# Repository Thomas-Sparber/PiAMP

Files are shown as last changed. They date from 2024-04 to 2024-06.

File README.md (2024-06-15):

# PiAMP



PiAMP is a DIY guitar amplifier which uses a neural network to emulate the sound of *any* guitar amplifier or pedal.

It consists of the following components
 - **Raspberry PI** which processes the audio, provides bluetooth connection and receives signals from the controls and footswitch
 - **HifibBerry DAC+ ADC** is the audio interface used for high quality audio
 - **Power amp** which converts the low level audio signal into a signal which can be fed into a speaker
 - **Speakers/Cabinet**
 - **Screen and controls** which allow to set the current Amp model, cabinet and other controls (gain, bas, mid, etc.)
 - **Footswitch** which allows to quickly switch between saved channels
 - **Bluetooth app** which allows to connect to the PiAMP and set its parameters via phone

Here a picture of my PiAMP with my DIY guitar

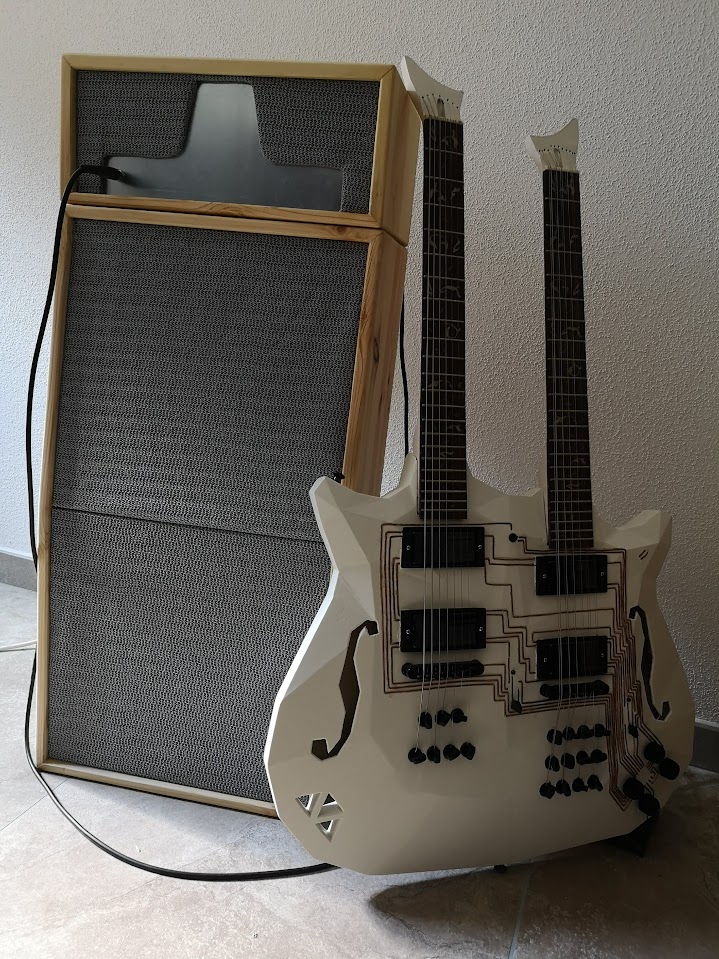
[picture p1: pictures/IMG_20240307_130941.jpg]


This is how it looks like when its turned on

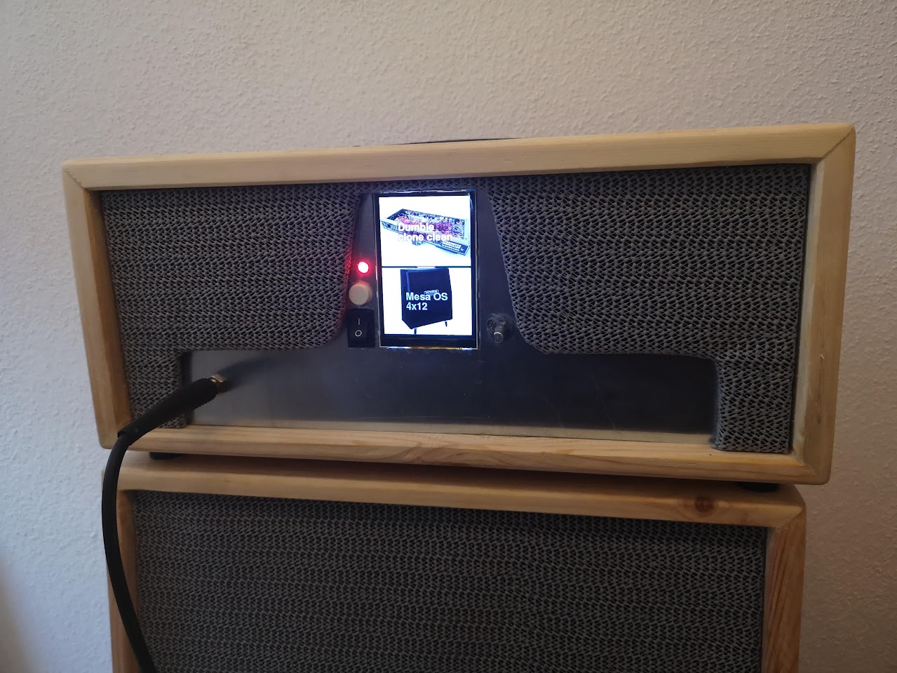
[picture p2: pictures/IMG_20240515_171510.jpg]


And here is a picture of the foot switch

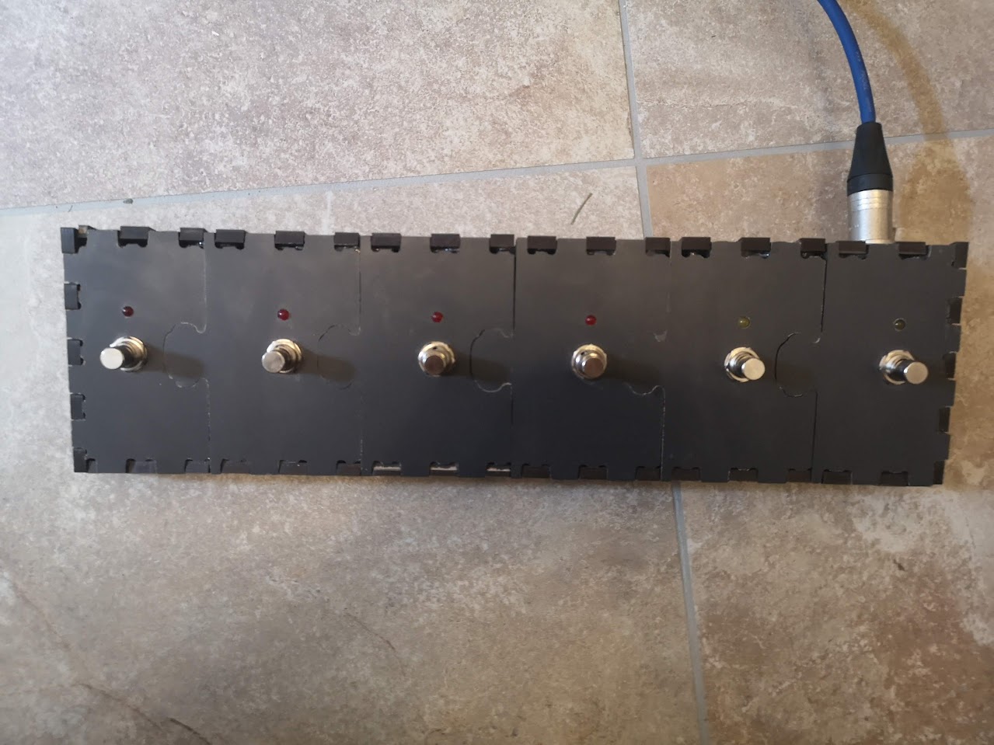
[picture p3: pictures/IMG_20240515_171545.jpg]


And finally, here a video which shows some more details of the PiAMP (and my DIY guitar) and a demo.
Please excuse me for the poor quality - I simply don't have the patience and skills to make a good video...

https://www.youtube.com/watch?v=HTpMu2ALkGg

## Disclaimer

This project is open source and everyone is very welcome to build its own PiAMP. Also everyone is very welcome to contribute to this project!

The following instructions are not (yet) meant to be complete, I'm just writing down what I remember from building my amp.
I am very happy to help you if you want to build your own amp - it would be great if you could contribute in creating a more comprehensive guide!

## Schematics and components used

Here is a very crude schematics of what's going on inside the PiAMP:

app

The Raspberry PI takes the input signals (guitar + line in) from the HifiBerry shield and processes the signals using the [NeuralPi](https://github.com/Thomas-Sparber/NeuralPi) [sushi](https://github.com/elk-audio/sushi) plugin. The processed audio signal leaves the PI again via the HifiBerry shield and enters the power amp which amplifies the signal and drives the speakers.

On the Raspberry PI there is also a [nodejs](https://nodejs.org/) service running which does the following things:
 - Controls the NeuralPi plugin using [OSC](https://de.wikipedia.org/wiki/Open_Sound_Control)
 - Provides bluetooth connection to allow connecting via app
 - Connects to an arduino mega via USB + serial to receive commands about changing parameters
 - Connects to the footswitch via USB + serial to receive commands about switching and saving channels

Here is the list of components I used. Please note that I don't want to promote products/sellers; these are just the components I used and most of them can be replaced with similar components:
 - [Raspberry PI 4](https://www.raspberrypi.com/products/raspberry-pi-4-model-b/)
 - [HifiBerry DAC* ADC](https://www.hifiberry.com/shop/boards/hifiberry-dac-adc/)
 - [Raspberry power supply](https://www.berrybase.at/offizielles-raspberry-pi-usb-c-netzteil-5-1v/3-0a-eu-schwarz?c=348)
 - [the t.amp TA50](https://www.thomann.de/at/the_tamp_ta50.htm)
 - 2x [Celestion BL15-300X 4 Ohm](https://www.thomann.de/at/celestion_bl15_300x_4_ohm.htm)

These were the mandatory components, now the optional components
 - [Arduino mega](https://store.arduino.cc/products/arduino-mega-2560-rev3) for the controls (screen + knobs)
 - [3.5inch Arduino display](http://www.lcdwiki.com/3.5inch_Arduino_Display-UNO)
 - [KY-040 rotary encoder](https://sensorkit.joy-it.net/en/sensors/ky-040)
 - [Turnigy TGY-1551A Analog Micro Servo](https://hobbyking.com/de_de/turnigy-tgy-1551a-analog-micro-servo-1-0kg-0-08sec-5g.html) for the knobs (gain, bass, mid etc.)
 - [Raspberry PI pico](https://www.raspberrypi.com/products/raspberry-pi-pico/) to run the foot switch. A small arduino should also be fine

Then you will also need a lot of accessoires and connectors. This depends a bit on how you want to build it, e.g.
 - A [cable](https://www.ebay.at/itm/381639249289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) to connect the HifiBerry shield to the power amp
 - [Jack connector](https://www.ebay.at/itm/402632877457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) for your guitar input. I also used these to connect the power amp output to the speakers
 - [Footswitch switches](https://www.ebay.at/itm/325064963804)
 - [XLR male](https://www.ebay.at/itm/360663764984) and [female](https://www.ebay.at/itm/200930409418) to connect the raspberry to the footswitch
 - [USB to TTL adapter](https://www.ebay.at/itm/255323594516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) to connect the raspberry to arduino + footswitch
 - LEDs, switches, cables, etc.
 - Wood or other material to build the frame, footswitch etc.
 - Several 3d printed parts (STL files in this repo)

## Setting up the Raspberry PI

Please follow the guide on Elk-Audio to set up your raspberry pi: [Guide](https://elk-audio.github.io/elk-docs/html/intro/getting_started_with_raspberry.html)

At the end you should have a Raspberry PI up and running elk os.

You need to have a `/udata/libs` folder on your pi. If not, create it by running

    sudo mkdir/udata/libs

Next go to [Releases](https://github.com/Thomas-Sparber/PiAMP/releases), and download all files to your PI, e.g. by using wget

    cd /udata/libs
    wget https://github.com/Thomas-Sparber/PiAMP/releases/download/1.0/NeuralPi.vst3.tgz
    wget ...

Next, install the sushi plugin by running

    tar xf NeuralPi.vst3.tgz
    mv NeuralPi.vst3 ~/plugins/NeuralPi.vst3

Copy the config file to its correct folder by running

    cp config_neuralpi.json ~/config_files/config_neuralpi.json

Finally, download some tones and Irs (Impule responses = Guitar cabinet emulations) and copy them into the corresponsing folders:

    mkdir -p ~/Documents/GuitarML/NeuralPi/tones
    mkdir -p ~/Documents/GuitarML/NeuralPi/irs

Tones/Models can be found on [GuitarML's home page](https://guitarml.com/tonelibrary/tonelib-pro.html). Both, Proteus and NeuralPi models can be used by PiAMP. Please check out his homepage, he did great things and research. The json files need to be copied into the tones folder on the PI created above

IRs can be found e.g. on [tonehunt](https://tonehunt.org/models?filter=ir). Please note that this webpage is actually for NAM but the IRs work anyways. The wav files need to be copied into the irs folder created above.

If you visit the [tonehunt](https://tonehunt.org/models?filter=ir) website to download IRs you will probably notice that there are MANY great amp models available too! Unfortunately they cannot be used directly. I tried to implement the whole NAM stack into PiAMP (and it also worked), but the CPU usage was too high on the raspberry so it couldn't properly handle them, so it didn't sound good. The good noews is that you can convert NAM models to NeuralPi/Proteus models. Please check out my [other repo](https://github.com/Thomas-Sparber/NAM_to_NeuralPi)

The next command enables the NeuralPi plugin on startup, see [here](https://elk-audio.github.io/elk-docs/html/documents/working_with_elk_board.html#configuring-automatic-startup)

    sudo cp sushi.service /lib/systemd/system/sushi.service
    sudo systemctl enable sushi

Then install the PiAMP server by running

    tar xf node-v20.9.0-linux-arm64.tar.xz
    tar xf piamp.tgz
    sudo cp piamp.service /lib/systemd/system/piamp.service
    sudo systemctl enable piamp

Now, as everything is installed you can start it by restarting you pi or running

    sudo systemctl start sushi
    sudo systemctl start piamp

Now as everything is up and running you can access the web interface of PiAMP by opening `http://<raspberry-ip-address>:3600/` in your browser.

Alternatively (/additionally) you can of yourse also install the mobile app on your phone by installing `app-debug.apk` on your phone. Please note that is app is not (yet) available from any app store (If PiAMP gets popular I will probably publish it), so you need to manually install it. Please check [online](https://stackoverflow.com/questions/15743391/i-want-to-install-an-unsigned-apk-file-on-my-mobile-what-to-do) how to install unsigned apk files on your phone.

## Some more pictures

Cutting out the aluminium front plate on my snapmaker

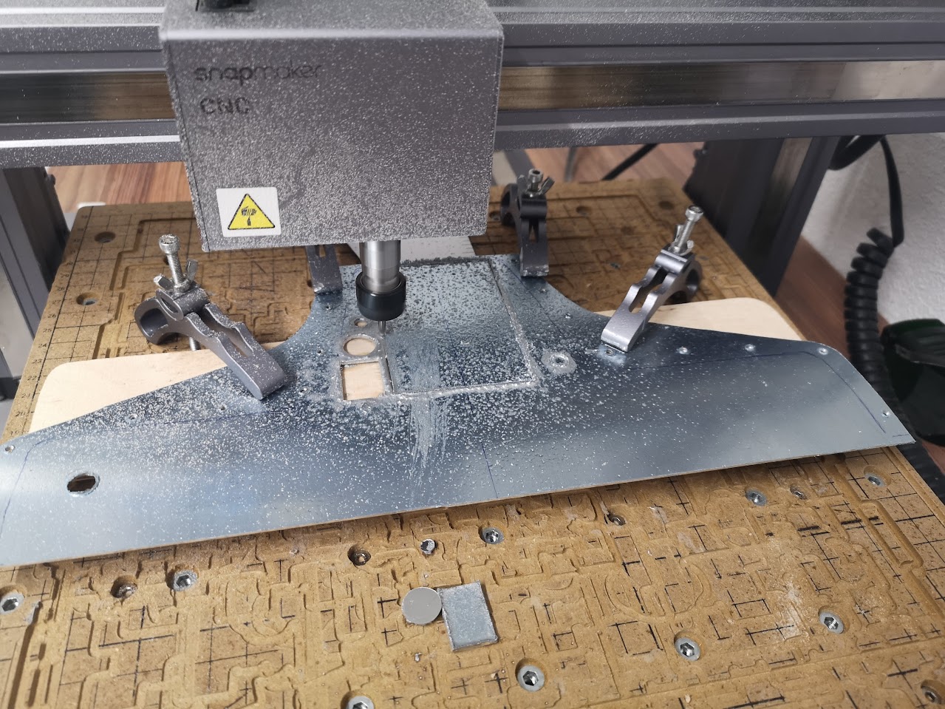
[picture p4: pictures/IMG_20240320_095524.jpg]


Opened mounted front plate

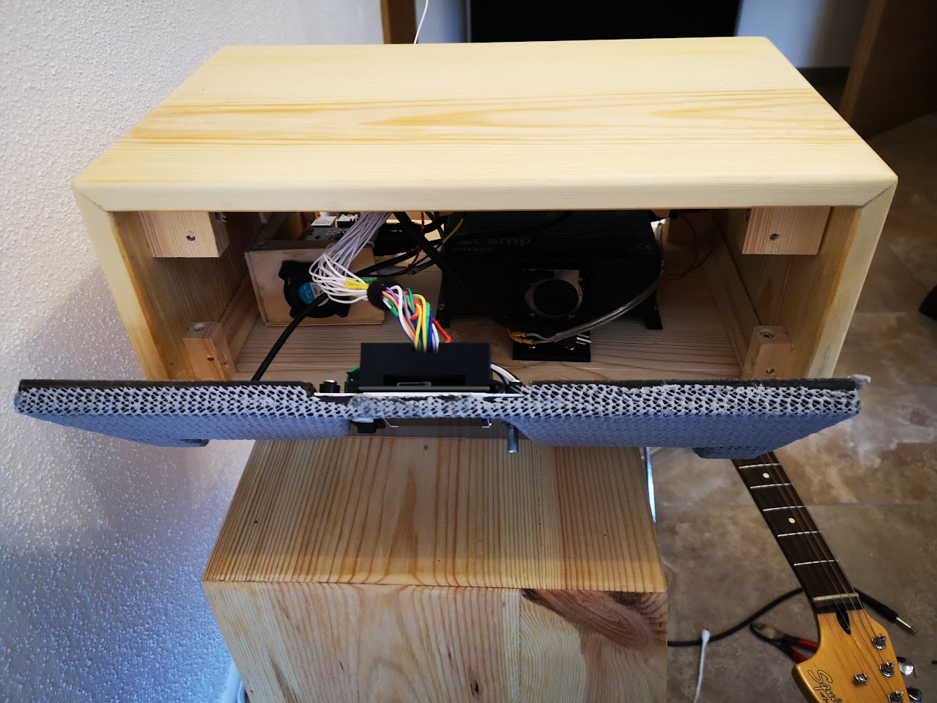
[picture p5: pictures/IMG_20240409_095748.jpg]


Back view

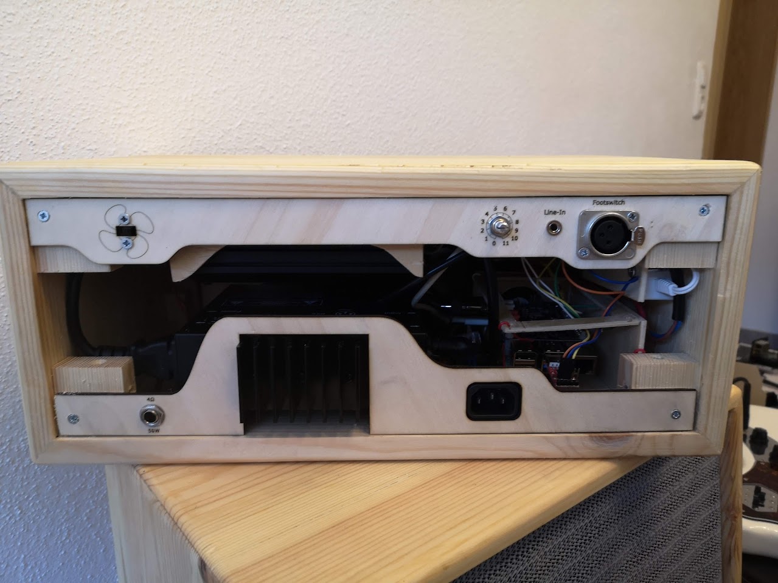
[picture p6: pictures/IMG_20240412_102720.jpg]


## Wiring diagrams

### HifiBerry Hat

You probably need to change the jumpers on the hat to enable 12db gain, please check the [datasheet](https://www.hifiberry.com/docs/data-sheets/datasheet-dac-adc/) how to do it

### Raspberry PI to footswitch connection

As already said I used an [USB to TTL adapter](https://www.ebay.at/itm/255323594516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) to connect the Raspberry to the Raspberry Pico (/arduino) of the foot switch. I connected the 5V+ out pin of the TTL adapter to the XLR + pin, the GND of the TTL adapter to the GND pin of the XLR connector and the RX pin of the TTL adapter to the remaining pin. On the other XLR connector I of course connected the same pins to the PI pico to power it and enable data transmission. XLR unforunately only has 3 pins so only one way communication (footswitch --> Raspberry PI) is possible

### Raspberry PI to Arduino (controls) connections

Here I also used the [USB to TTL adapter](https://www.ebay.at/itm/255323594516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) and connectoed TTL GND to arduino GND and TTL RX to arduino TX and TTL TX to arduino RX. This makes two way communication possible.

### Arduino (Controls) wiring diagram

This section describes how to connect the display and the servos to the arduino. Unfortunately it is not yet done. If you want to contribute, please let me know

### Poweroff button

The poweroff button is used to power off the PI to enable a smooth shutdown before power is disconnected. A simple push button needs to be connected to GPIO4 and GND. If the button is pressed, the PI shuts down. 

### Cooling fan(s)

I added some additional old laptop cooling fans to the PI and the power amp to prevent overheating. I think this is more of an optional step.

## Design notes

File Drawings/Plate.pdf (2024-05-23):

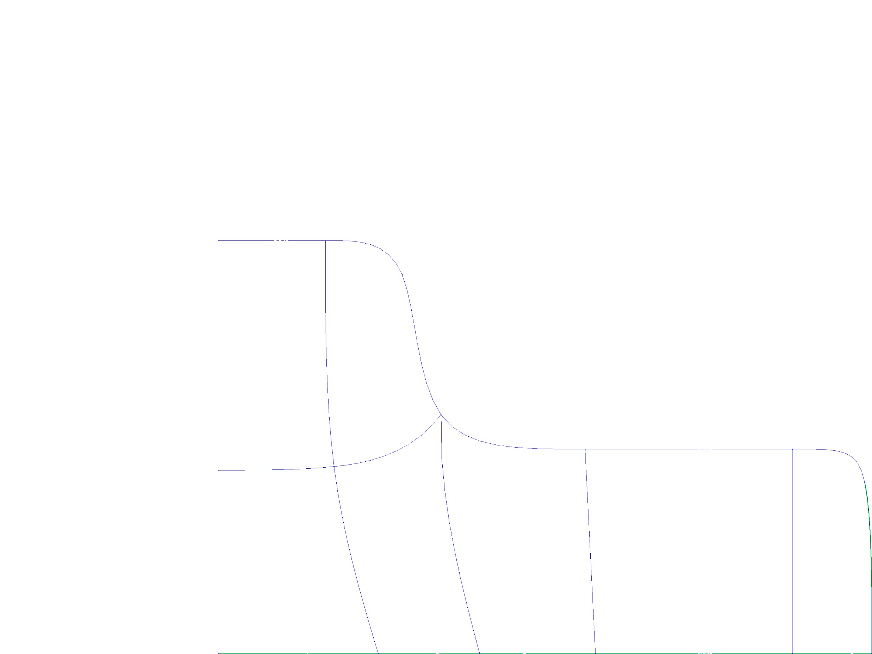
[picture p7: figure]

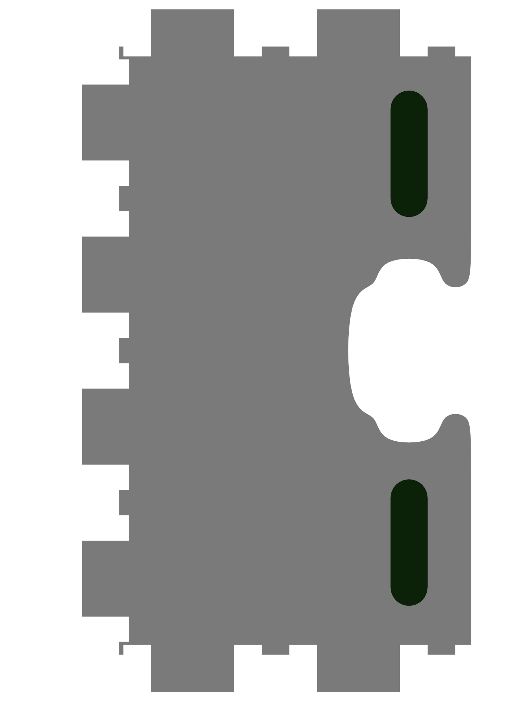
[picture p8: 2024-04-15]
Drawings/Footswitch/Footswitch-1.0.png

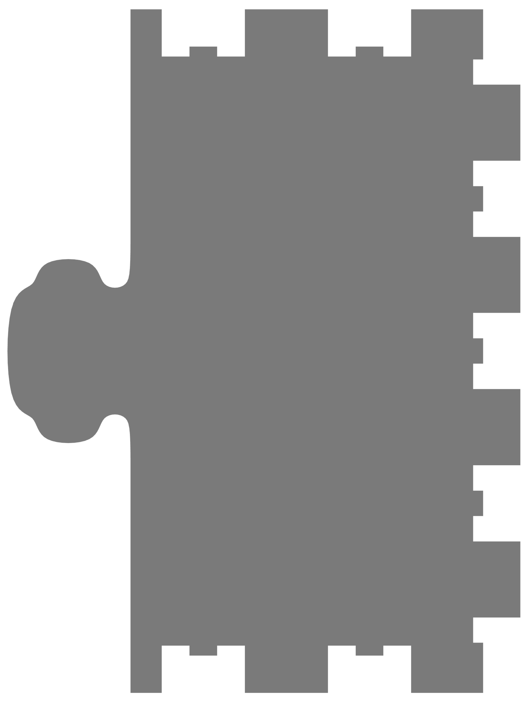
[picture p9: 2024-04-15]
Drawings/Footswitch/Footswitch-3.0.png

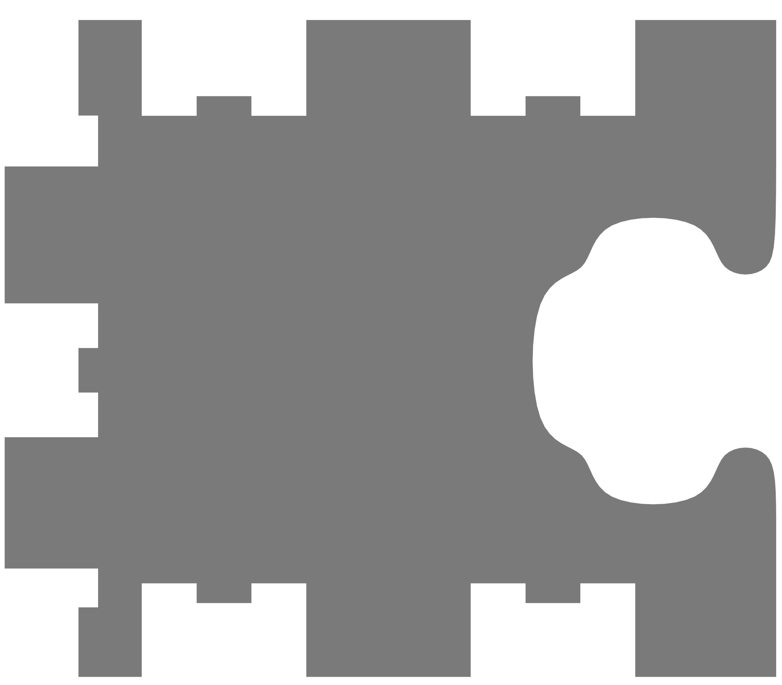
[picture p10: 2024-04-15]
Drawings/Footswitch/Footswitch-1.2.png

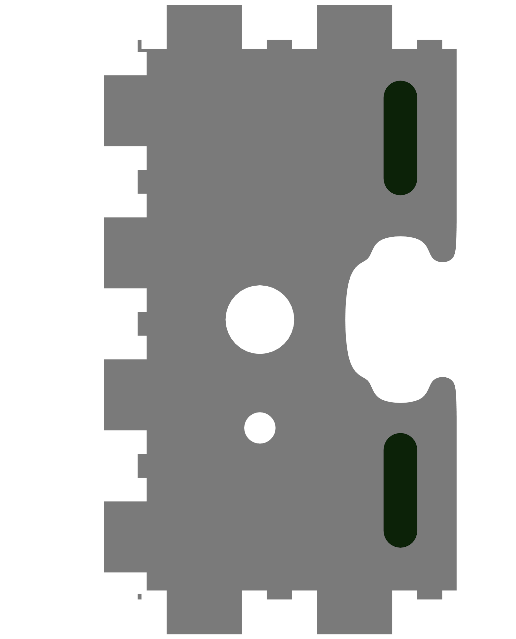
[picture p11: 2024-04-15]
Drawings/Footswitch/Footswitch-1.1.png

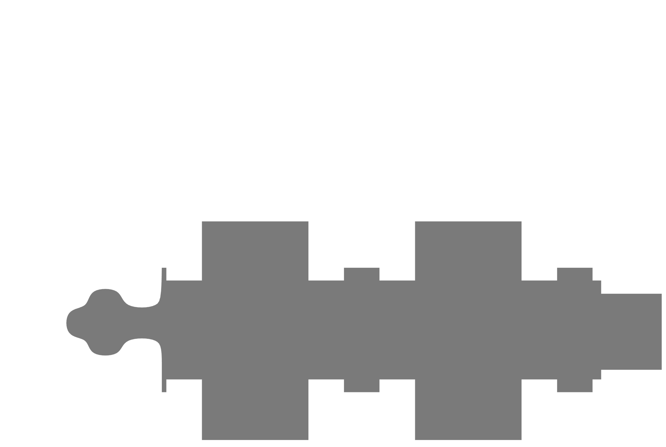
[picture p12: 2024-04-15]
Drawings/Footswitch/Footswitch-3.3.png

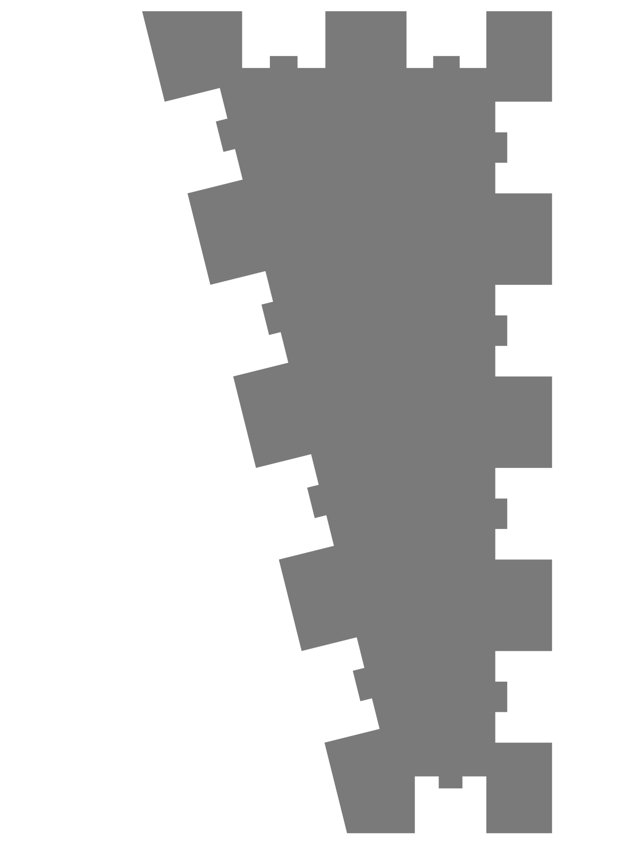
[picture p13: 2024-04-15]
Drawings/Footswitch/Footswitch-1.5.png

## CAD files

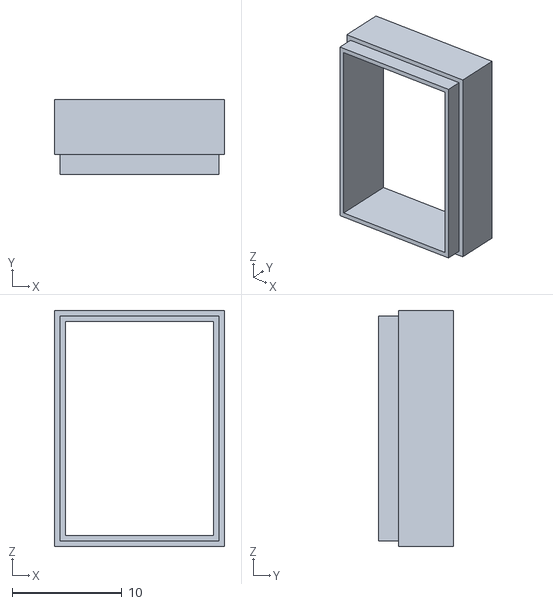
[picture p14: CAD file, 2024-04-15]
Drawings/main-switch-holder.stl
15.5 x 6.80 x 21.5

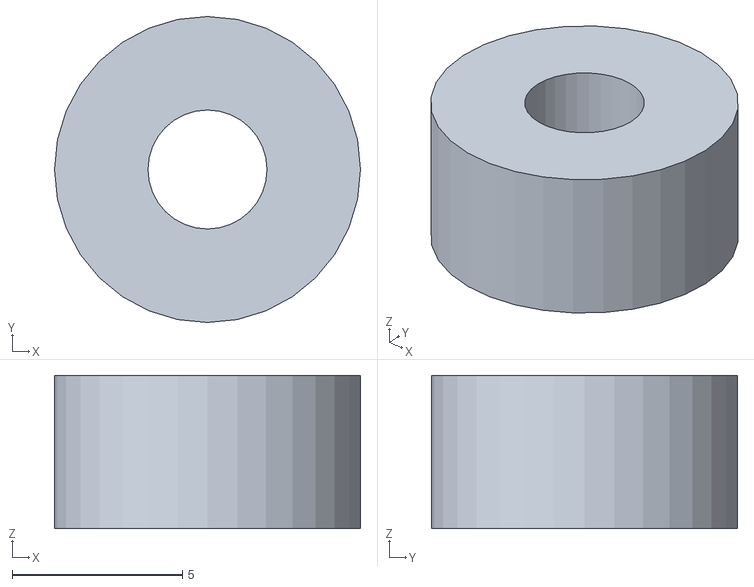
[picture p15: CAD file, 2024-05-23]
Drawings/spacer.stl
9.00 x 9.00 x 4.50

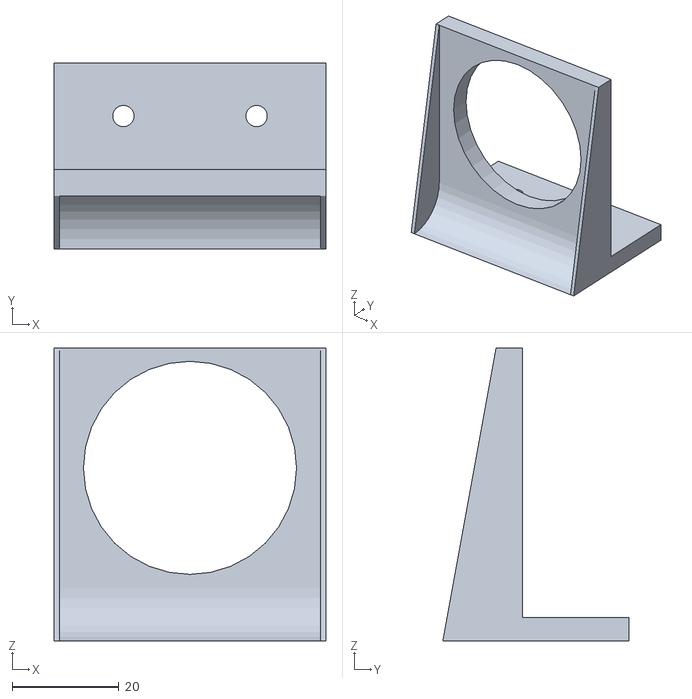
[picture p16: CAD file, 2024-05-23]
Drawings/fan-holder.stl
51.0 x 35.0 x 55.0

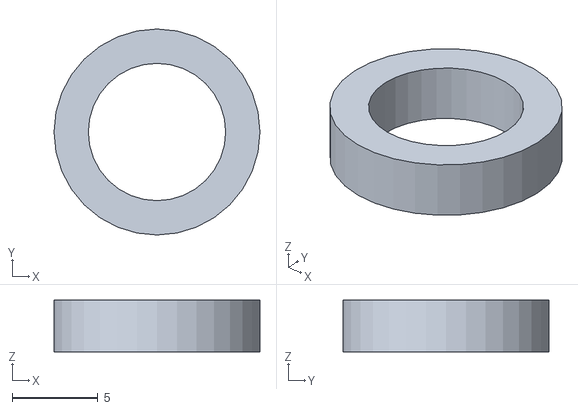
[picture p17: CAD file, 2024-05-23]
Drawings/Spacer-encoder.stl
12.0 x 12.0 x 3.00

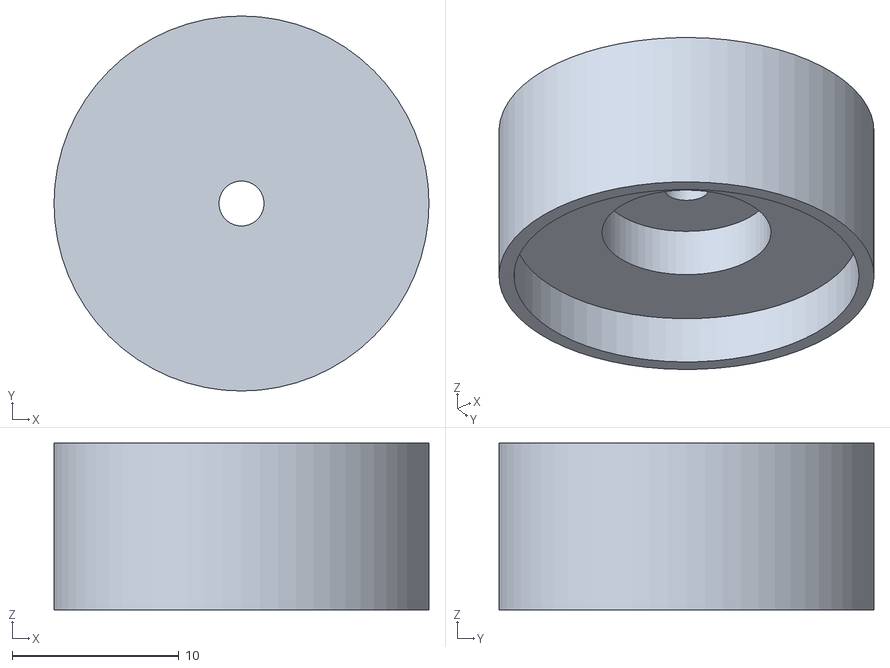
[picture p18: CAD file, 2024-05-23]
Drawings/feet.stl
22.5 x 22.5 x 10.0

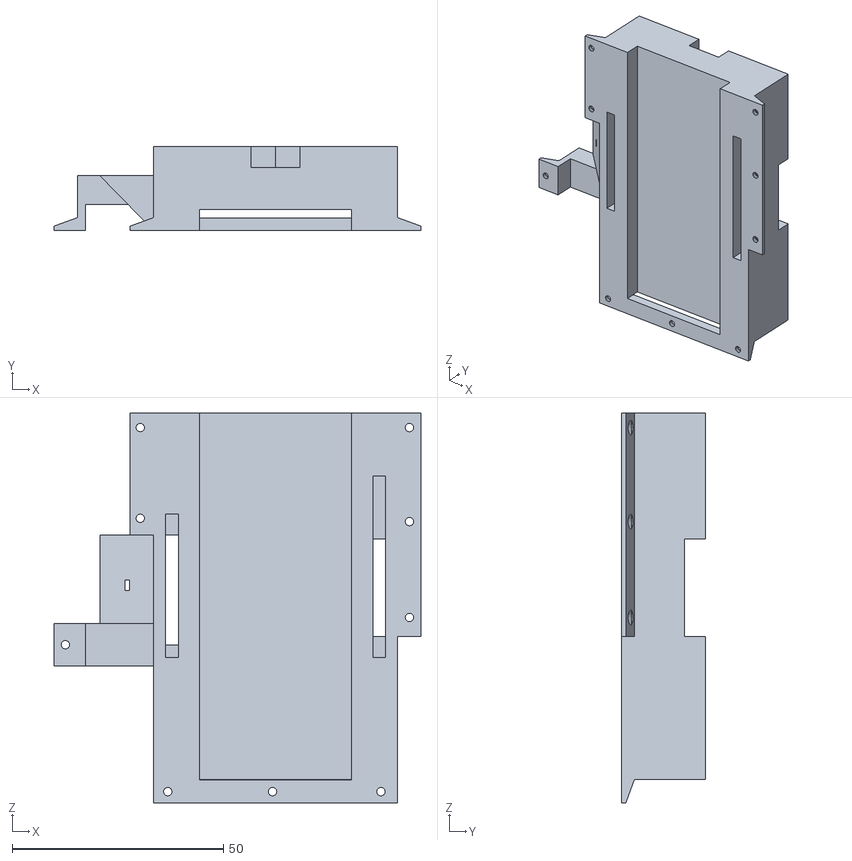
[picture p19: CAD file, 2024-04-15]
Drawings/screen-holder1.stl
86.8 x 19.8 x 92.2

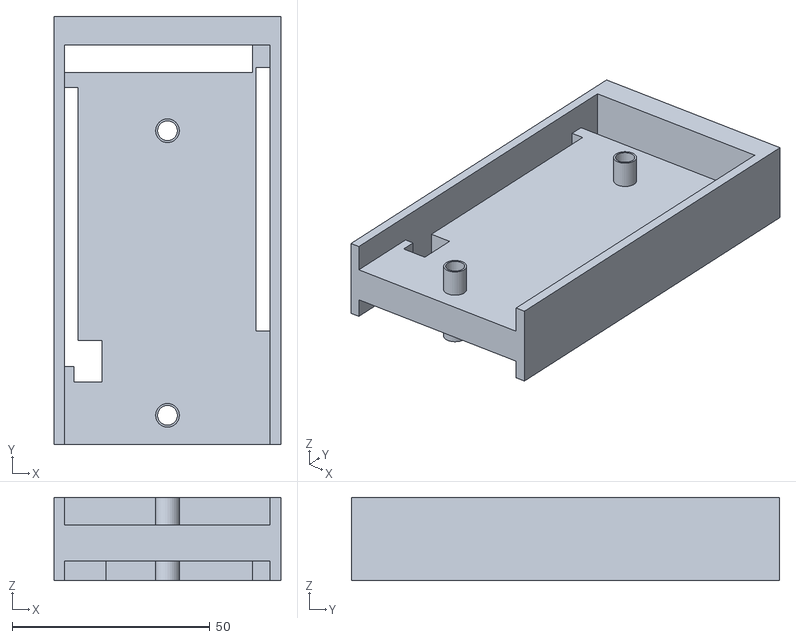
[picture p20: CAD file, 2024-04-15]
Drawings/arduino-holder.stl
57.3 x 108.1 x 21.0

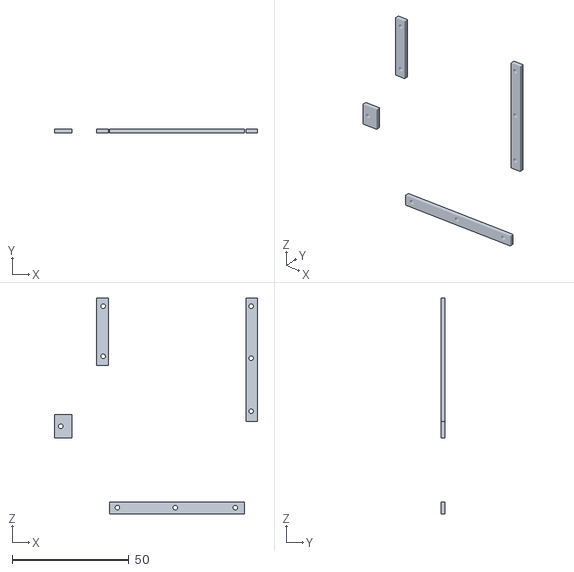
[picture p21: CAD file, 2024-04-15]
Drawings/screen-holder2.stl
86.8 x 1.90 x 92.2

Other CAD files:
Drawings/piamp.blend

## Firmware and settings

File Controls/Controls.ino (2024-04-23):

/***********************************************************************************
*                  LCD_CS  LCD_CD  LCD_WR  LCD_RD  LCD_RST  SD_SS  SD_DI  SD_DO  SD_SCK 
*     Arduino Uno    A3      A2      A1      A0      A4      10     11     12      13                            
*
*                  LCD_D0  LCD_D1  LCD_D2  LCD_D3  LCD_D4  LCD_D5  LCD_D6  LCD_D7  
*     Arduino Uno    8       9       2       3       4       5       6       7
**********************************************************************************/

#include "drawcommand.h"
#include "font.h"
#include "Fonts/FreeSansBold18pt7b.h"
#include "graphicsbackground.h"
#include "graphicsborder.h"
#include "graphicsimagewithouttext.h"
#include "graphicsliststatic.h"
#include "graphicsliststreaming.h"
#include "graphicstextandimage.h"
#include "utils.h"

#include <RotaryEncoder.h>
#include <LinkedList.h>
#include <ArduinoJson.h>
#include <base64.hpp>
#include <LCDWIKI_GUI.h> //Core graphics library
#include <LCDWIKI_KBV.h> //Hardware-specific library

#define SWITCH_CLK 20
#define SWITCH_DT 19
#define SWITCH_SW 21
#define LOADING_CIRCLE_RADIUS 30
#define BORDER_THICKNESS 4

#define MODEL_ID "Model"
#define IR_ID "Ir"

enum class Selection
{
  Model,
  Ir,
  ModelIrList,
  ModelList,
  IrList
};

LCDWIKI_KBV mylcd(ILI9486,A3,A2,A1,A0,A4); //model,cs,cd,wr,rd,reset

LinkedList<Graphics*> drawQueue;
LinkedList<DrawCommand*> drawCommands;
LinkedList<String> serialCommands;
Font font(&drawPixel, &drawRect);

GraphicsBorder modelBorder;
GraphicsBorder irBorder;
GraphicsTextAndImage modelGraphics(&font);
GraphicsTextAndImage irGraphics(&font);
GraphicsImageWithoutText modelBackgroundGraphics(&font);
GraphicsImageWithoutText irBackgroundGraphics(&font);

GraphicsListStatic modelIrList(&font);
GraphicsListStreaming modelList(&font, "getmodels");
GraphicsListStreaming irList(&font, "getirs");

RotaryEncoder encoder(SWITCH_DT, SWITCH_CLK, RotaryEncoder::LatchMode::FOUR3);
volatile bool pi_available;
volatile unsigned long last_pi_response;
bool modelLoaded = false;
bool irLoaded = false;
bool encoderPressed = false;
Selection currentSelection = Selection::Model;

void drawRect(int16_t x, int16_t y, int16_t width, int16_t height, int16_t color)
{
  mylcd.Set_Draw_color(color);
  mylcd.Fill_Rectangle(x, y, width, height);
}

void drawPixel(int16_t x, int16_t y, uint16_t color)
{
  mylcd.Draw_Pixe(x, y, color);
}

void repaint(uint16_t x, uint16_t y, uint16_t w, uint16_t h)
{
  const unsigned char selected_background_color_r = 95;
  const unsigned char selected_background_color_g = 5;
  const unsigned char selected_background_color_b = 32;
  
  const unsigned char nonselected_background_color_r = 50;
  const unsigned char nonselected_background_color_g = 50;
  const unsigned char nonselected_background_color_b = 50;

  const unsigned char selected_text_color_r = 255;
  const unsigned char selected_text_color_g = 255;
  const unsigned char selected_text_color_b = 255;
  
  const unsigned char nonselected_text_color_r = 200;
  const unsigned char nonselected_text_color_g = 200;
  const unsigned char nonselected_text_color_b = 200;

  modelBorder.setOutset(currentSelection == Selection::Model);
  irBorder.setOutset(currentSelection == Selection::Ir);

  modelGraphics.setBackgroundColor(
    (currentSelection == Selection::Model) ? selected_background_color_r : nonselected_background_color_r,
    (currentSelection == Selection::Model) ? selected_background_color_g : nonselected_background_color_g,
    (currentSelection == Selection::Model) ? selected_background_color_b : nonselected_background_color_b
  );
  modelGraphics.setTextColor(
    (currentSelection == Selection::Model) ? selected_text_color_r : nonselected_text_color_r,
    (currentSelection == Selection::Model) ? selected_text_color_g : nonselected_text_color_g,
    (currentSelection == Selection::Model) ? selected_text_color_b : nonselected_text_color_b
  );
  
  irGraphics.setBackgroundColor(
    (currentSelection == Selection::Ir) ? selected_background_color_r : nonselected_background_color_r,
    (currentSelection == Selection::Ir) ? selected_background_color_g : nonselected_background_color_g,
    (currentSelection == Selection::Ir) ? selected_background_color_b : nonselected_background_color_b
  );
  irGraphics.setTextColor(
    (currentSelection == Selection::Ir) ? selected_text_color_r : nonselected_text_color_r,
    (currentSelection == Selection::Ir) ? selected_text_color_g : nonselected_text_color_g,
    (currentSelection == Selection::Ir) ? selected_text_color_b : nonselected_text_color_b
  );

  for(int i = 0; i < drawQueue.size(); ++i)
  {
    Graphics *g = drawQueue.get(i);
    if(!g->isValid())
    {
      g->createDrawCommands(&drawCommands, x, y, w, h, mylcd.Get_Display_Width(), mylcd.Get_Display_Height());
    }
  }
  
  Utils::log(drawCommands.size() + " draw commands");
}

void repaint()
{
  repaint(0, 0, mylcd.Get_Display_Width(), mylcd.Get_Display_Height());
}

void repaintAll(uint16_t x, uint16_t y, uint16_t w, uint16_t h)
{
  for(int i = 0; i < drawQueue.size(); ++i)
  {
    Graphics *g = drawQueue.get(i);
    g->invalidate();
  }

  repaint(x, y, w, h);
}

void repaintAll()
{
  repaintAll(0, 0, mylcd.Get_Display_Width(), mylcd.Get_Display_Height());
}

void readCurrentModelIr(const char *action, String *id, String *name, String *image)
{
  char command[256];
  snprintf(command, 256, "{\"action\":\"%s\"}", action);
  Serial.println(command);
  Utils::readSerialLine(command, 256);
  
  JsonDocument doc;
  deserializeJson(doc, command);

  if(id)
  {
    const char *tempId = doc["id"];
    (*id) = tempId;
  }

  if(name)
  {
    const char *tempName = doc["name"];
    (*name) = tempName;
  }

  if(image)
  {
    const char *tempImage = doc["image"];
    (*image) = tempImage;
  }
}

void setupScreen()
{
  drawQueue.clear();

  if(currentSelection == Selection::Model || currentSelection == Selection::Ir)
  {
    modelBorder.setX(0);
    modelBorder.setY(0);
    modelBorder.setW(mylcd.Get_Display_Width());
    modelBorder.setH(mylcd.Get_Display_Height()/2);
    modelBorder.setBorderThickness(BORDER_THICKNESS);

    irBorder.setX(0);
    irBorder.setY(mylcd.Get_Display_Height()/2);
    irBorder.setW(mylcd.Get_Display_Width());
    irBorder.setH(mylcd.Get_Display_Height()/2);
    irBorder.setBorderThickness(BORDER_THICKNESS);

    modelGraphics.setOffsetY(0);
    modelBackgroundGraphics.setOffsetY(0);
    modelBackgroundGraphics.setMargin(BORDER_THICKNESS);
    
    irGraphics.setOffsetY(mylcd.Get_Display_Height()/2);
    irBackgroundGraphics.setOffsetY(mylcd.Get_Display_Height()/2);
    irBackgroundGraphics.setMargin(BORDER_THICKNESS);
    
    drawQueue.add(&modelBorder);
    drawQueue.add(&irBorder);
    drawQueue.add(&modelGraphics);
    drawQueue.add(&irGraphics);
    drawQueue.add(&modelBackgroundGraphics);
    drawQueue.add(&irBackgroundGraphics);
  }

  if(currentSelection == Selection:: ModelIrList)
  {
    modelIrList.clearList();
    modelIrList.setX(0);
    modelIrList.setX(0);
    modelIrList.setW(mylcd.Get_Display_Width());
    modelIrList.setH(mylcd.Get_Display_Height());
    modelIrList.setSelectedColor(95, 5, 32);
    modelIrList.setBackgroundColor(0, 0, 0);
    modelIrList.setTextColor(255, 255, 255);
    modelIrList.addEntry(MODEL_ID, "Model");
    modelIrList.addEntry(IR_ID, "Impulse Response");
    modelIrList.setCurrentSelection(0);
    
    drawQueue.add(&modelIrList);
  }
  
  if(currentSelection == Selection:: ModelList)
  {
    modelList.setX(0);
    modelList.setX(0);
    modelList.setW(mylcd.Get_Display_Width());
    modelList.setH(mylcd.Get_Display_Height());
    modelList.setSelectedColor(95, 5, 32);
    modelList.setBackgroundColor(0, 0, 0);
    modelList.setTextColor(255, 255, 255);
    String id;
    readCurrentModelIr("getmodel", &id, NULL, NULL);
    modelList.setCurrentId(id);
    
    drawQueue.add(&modelList);
  }
  
  if(currentSelection == Selection:: IrList)
  {
    irList.setX(0);
    irList.setX(0);
    irList.setW(mylcd.Get_Display_Width());
    irList.setH(mylcd.Get_Display_Height());
    irList.setSelectedColor(95, 5, 32);
    irList.setBackgroundColor(0, 0, 0);
    irList.setTextColor(255, 255, 255);
    String id;
    readCurrentModelIr("getir", &id, NULL, NULL);
    irList.setCurrentId(id);
    
    drawQueue.add(&irList);
  }
}

void setup() 
{
  Serial.begin(115200);
  mylcd.Init_LCD();

  pi_available = false;
  
  font.setFont(&FreeSansBold18pt7b);

  pinMode(SWITCH_SW, INPUT);
  attachInterrupt(digitalPinToInterrupt(SWITCH_SW), encoderInterrupt, FALLING);
  attachInterrupt(digitalPinToInterrupt(SWITCH_CLK), encoderCheckPosition, CHANGE);
  attachInterrupt(digitalPinToInterrupt(SWITCH_DT), encoderCheckPosition, CHANGE);

  mylcd.Fill_Screen(0x0000);
  setupScreen();
}

void handleCommand(const char *command) {
  JsonDocument doc;
  deserializeJson(doc, command);

  const char *action = doc["action"];

  //if(strcmp(action, "pong") != 0 && strcmp(action, "null") != 0 && strcmp(action, "") != 0)Utils::log("New command " ,action);
  
  if(strcmp(action, "pong") == 0)
  {
    last_pi_response = millis();
    if(!pi_available)Utils::log("Pi online");
    pi_available = true;
    
    if(!modelLoaded)
    {
      serialCommands.add("{\"action\":\"getmodel\"}");
    }
    if(modelLoaded && !irLoaded)
    {
      serialCommands.add("{\"action\":\"getir\"}");
    }
  }

  if(strcmp(action, "model") == 0)
  {
    modelLoaded = true;
    const char *tempId = doc["id"];
    const char *tempModel = doc["name"];
    const char *tempImage = doc["image"];
    modelGraphics.setText(tempModel);
    modelBackgroundGraphics.setText(tempModel);
    modelGraphics.setImageStr(tempImage);
    modelBackgroundGraphics.setImageStr(tempImage);
    modelList.setCurrentId(tempId);
    Utils::log("New model loaded: ", tempModel);
    clearDrawCommands();
    addDrawCommandSleep(100);
    repaint();
  }

  if(strcmp(action, "ir") == 0)
  {
    irLoaded = true;
    const char *tempId = doc["id"];
    const char *tempIr = doc["name"];
    const char *tempImage = doc["image"];
    irGraphics.setText(tempIr);
    irBackgroundGraphics.setText(tempIr);
    irGraphics.setImageStr(tempImage);
    irBackgroundGraphics.setImageStr(tempImage);
    irList.setCurrentId(tempId);
    Utils::log("New ir loaded: ", tempIr);
    clearDrawCommands();
    addDrawCommandSleep(100);
    repaint();
  }
}

void handleSerial() {
  bool waitingResponse = false;
  if(serialCommands.size() != 0)
  {
    const String command = serialCommands.shift();
    Serial.println(command);
    waitingResponse = true;
  }
  else if(pi_available)
  {
    Serial.println("{\"action\":\"getcommands\"}");
    waitingResponse = true;
  }

  static char currentCommand[256];
  static int currentPosition = 0;

  const int timeout = 500;
  unsigned long startTime = millis();
  
  do {
    while(waitingResponse && Serial.available() == 0) {
      delay(1);
  
      if(millis() >= startTime + timeout)
      {
        Utils::log("Read timeout");
        return;
      }
    }
    
    while(Serial.available() > 0) {
      last_pi_response = millis();
      int b = Serial.read();
      currentCommand[currentPosition++] = (char)b;
  
      if(currentPosition == 256)currentPosition = 0;
  
      if(b == '\n') {
        currentCommand[currentPosition] = '\0';
        currentPosition = 0;
        handleCommand(currentCommand);
        waitingResponse = false;
      }
    }
  }
  while(waitingResponse);
}

void handleDrawCommands(int diff)
{
  if(drawCommands.size() != 0)
  {
    if(drawCommands.get(0)->type == DrawCommandType::Sleep)
    {
      DrawCommandSleep *s = static_cast<DrawCommandSleep*>(drawCommands.get(0)->data);
      s->milliseconds -= diff;
      if(s->milliseconds > 0)return;
    }
    
    DrawCommand *command = drawCommands.shift();
    command->data->handle(&mylcd, &font, command->x, command->y, command->w, command->h);
    ReusableDrawCommands::put(command->type, command->data);
    ReusableDrawCommands::put(command);

    last_pi_response = millis();
    
    if(drawCommands.size() == 0)Utils::log("Finished rendering");
  }
}

void changeModel(int diff)
{
  clearDrawCommands();

  char temp[256];
  snprintf(temp, 256, "{\"action\":\"modelchange\",\"value\":%d}", diff);
  serialCommands.add(temp);
}

void changeModel(const String &model)
{
  clearDrawCommands();

  char temp[256];
  snprintf(temp, 256, "{\"action\":\"modelchange\",\"model\":\"%s\"}", model.c_str());
  serialCommands.add(temp);
}

void changeIr(int diff)
{
  clearDrawCommands();

  char temp[256];
  snprintf(temp, 256, "{\"action\":\"irchange\",\"value\":%d}", diff);
  serialCommands.add(temp);
}

void changeIr(const String &ir)
{
  clearDrawCommands();

  char temp[256];
  snprintf(temp, 256, "{\"action\":\"irchange\",\"ir\":\"%s\"}", ir.c_str());
  serialCommands.add(temp);
}

void handleEncoder()
{
  static long oldPosition = encoder.getPosition();
  encoder.tick();
  
  long newPosition = encoder.getPosition();

  if (newPosition != oldPosition)
  {
    const long diff = newPosition - oldPosition;
    if(currentSelection == Selection::Model)
    {
      changeModel(diff);
    }
    else if(currentSelection == Selection::Ir)
    {
      changeIr(diff);
    }
    else if(currentSelection == Selection::ModelIrList)
    {
      clearDrawCommands();
      modelIrList.incrementCurrentSelection(diff);
      repaint();
    }
    else if(currentSelection == Selection::ModelList)
    {
      clearDrawCommands();
      modelList.incrementCurrentSelection(diff);
      repaint();
    }
    else if(currentSelection == Selection::IrList)
    {
      clearDrawCommands();
      irList.incrementCurrentSelection(diff);
      repaint();
    }
    oldPosition = newPosition;
    Utils::log("Encoder: " + diff);
  }

  if(encoderPressed)
  {
    encoderPressed = false;
    
    if(currentSelection == Selection::Model)
    {
      currentSelection = Selection::Ir;
      clearDrawCommands();
      repaint();
    }
    else if(currentSelection == Selection::Ir)
    {
      currentSelection = Selection::ModelIrList;
      mylcd.Fill_Screen(0x0000);
      setupScreen();
      clearDrawCommands();
      repaintAll();
    }
    else if(currentSelection == Selection::ModelIrList)
    {
      const String &selected = modelIrList.getCurrentId();
      if(selected == MODEL_ID)
        currentSelection = Selection::ModelList;
      else
        currentSelection = Selection::IrList;
        
      mylcd.Fill_Screen(0x0000);
      setupScreen();
      clearDrawCommands();
      repaintAll();
    }
    else if(currentSelection == Selection::ModelList)
    {
      String id;
      readCurrentModelIr("getmodel", &id, NULL, NULL);
      if(id != modelList.getCurrentId())
      {
        changeModel(modelList.getCurrentId());
      }
      else
      {
        currentSelection = Selection::Model;
        mylcd.Fill_Screen(0x0000);
        setupScreen();
        clearDrawCommands();
        repaintAll();
      }
    }
    else if(currentSelection == Selection::IrList)
    {
      String id;
      readCurrentModelIr("getir", &id, NULL, NULL);
      if(id != irList.getCurrentId())
      {
        changeIr(irList.getCurrentId());
      }
      else
      {
        currentSelection = Selection::Model;
        mylcd.Fill_Screen(0x0000);
        setupScreen();
        clearDrawCommands();
        repaintAll();
      }
    }
  }
}

int freeRam() {
  extern int __heap_start,*__brkval;
  int v;
  return (int)&v - (__brkval == 0 ? (int)&__heap_start : (int) __brkval);  
}

void handlePing()
{
  static unsigned long lastPing = 0;
  const unsigned long currentTime = millis();

  if(currentTime - last_pi_response > 5000)
  {
    if(pi_available)Utils::log("Pi went offline");
    pi_available = false;
  }

  if(currentTime - last_pi_response > 2000 && currentTime - lastPing > 1000)
  {
    Serial.println("{\"action\":\"ping\"}");
    lastPing = currentTime;
  }
}

void checkFreeMem() {
  static unsigned long lastPrint = 0;
  const unsigned long currentTime = millis();

  if(currentTime - lastPrint > 1000)
  {
    Utils::log("Free mem ", freeRam());
    lastPrint = currentTime;
  }
}

void clearDrawCommands()
{
  while(drawCommands.size() != 0)
  {
    DrawCommand *command = drawCommands.shift();
    ReusableDrawCommands::put(command->type, command->data);
    ReusableDrawCommands::put(command);
  }

  Utils::log("Draw commands cleared");
}

void addDrawCommandSleep(int ms)
{
  if(drawCommands.size() != 0 && drawCommands.get(0)->type == DrawCommandType::Sleep)
  {
    DrawCommandSleep *s = static_cast<DrawCommandSleep*>(drawCommands.get(0)->data);
    s->milliseconds = ms;
  }
  else
  {
    drawCommands.add(DrawCommandSleep::create(ms));
  }
}

void showLoading() {
  static float radius = 0;
  const int count = 11;
  const float angles[] = { -1.0, -0.9, -0.8, -0.7, -0,6, -0.5, -0.4, -0.3, -0.2, -0.1, 0.0 };
  const uint16_t colors[] = {
    mylcd.Color_To_565(189,   9,  64),
    mylcd.Color_To_565(189,   9,  64),
    mylcd.Color_To_565(194,  29,  79),
    mylcd.Color_To_565(199,  49,  94),
    mylcd.Color_To_565(204,  69, 109),
    mylcd.Color_To_565(209,  89, 124),
    mylcd.Color_To_565(214, 109, 139),
    mylcd.Color_To_565(219, 129, 154),
    mylcd.Color_To_565(224, 149, 169),
    mylcd.Color_To_565(229, 169, 184),
    mylcd.Color_To_565(234, 189, 199)
  };

  for(int i = 0; i < count; ++i)
  {
    int x = mylcd.Get_Display_Width()/2 + cos(radius + angles[i]) * LOADING_CIRCLE_RADIUS;
    int y = mylcd.Get_Display_Height()/2 + sin(radius + angles[i]) * LOADING_CIRCLE_RADIUS;
    
    mylcd.Set_Draw_color(colors[i]);
    mylcd.Fill_Rectangle(x - 1, y - 1, x + 1, y + 1);
  }

  delay(50);
  radius += 0.2;
}

void loop() 
{
  static bool last_pi_available = false;
  static unsigned long lastTime = millis();
  const unsigned long currentTime = millis();
  const int diff = currentTime - lastTime;
  lastTime = currentTime;
  
  handleEncoder();
  handleSerial();
  handlePing();
  checkFreeMem();

  if(pi_available)
  {
    if(!last_pi_available)
    {
      repaint(mylcd.Get_Display_Width()/2 - LOADING_CIRCLE_RADIUS - 1, mylcd.Get_Display_Height()/2 - LOADING_CIRCLE_RADIUS - 1, LOADING_CIRCLE_RADIUS * 2 + 2, LOADING_CIRCLE_RADIUS * 2 + 2);
    }
    
    handleDrawCommands(diff);
  }
  else
  {
    showLoading();
  }
  last_pi_available = pi_available;
}

void encoderInterrupt()
{
  encoderPressed = true;
}

void encoderCheckPosition()
{
  encoder.tick();
}

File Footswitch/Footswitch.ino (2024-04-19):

#include <ArduinoJson.h>

#include "channel.h"

Channel channels[] = {
  Channel(
    "CH1",  //name
    11,     //switchPin
    10,     //ledPin
    true,   //hasSubChannel
    false   //isFxChannel
  ),
  Channel(
    "CH2",  //name
    9,      //switchPin
    8,      //ledPin
    true,   //hasSubChannel
    false   //isFxChannel
  ),
  Channel(
    "CH3",  //name
    7,      //switchPin
    6,      //ledPin
    true,   //hasSubChannel
    false   //isFxChannel
  ),
  Channel(
    "CH4",  //name
    13,     //switchPin
    12,     //ledPin
    true,   //hasSubChannel
    false   //isFxChannel
  ),

  Channel(
    "FX1",  //name
    5,      //switchPin
    4,      //ledPin
    false,  //hasSubChannel
    true    //isFxChannel
  ),
  Channel(
    "FX2",  //name
    3,      //switchPin
    2,      //ledPin
    false,  //hasSubChannel
    true    //isFxChannel
  )
};

//Defines the time in milliseconds how long the led
//should be on and off for the sub channel blinking
int subBlinkTimeMillis = 200;

//Defines how long the switch needs to be pressed to save the channel
int saveTimeMillis = 5000;

//When the switch is pressed the saving action is indicated by fast led blinking.
//The blinking time is indicated by this variable
int saveBlinkTimeMillis = 20;

//The save-blinking should not start right away but after the following time
int saveTimeStartMillis = 1000;

int channelsCount = sizeof(channels) / sizeof(struct Channel);
int lastTimeMillis;
String lastSentCommand;
String currentCommand;

void setup() {
  //Serial1.setRX(1);
  //Serial1.setTX(0);
  Serial1.begin(115200);
  pinMode(LED_BUILTIN, OUTPUT);

  for(int i = 0; i < channelsCount; ++i) {
    pinMode(channels[i].switchPin, INPUT_PULLUP);
    pinMode(channels[i].ledPin, OUTPUT);

    digitalWrite(channels[i].ledPin, LOW);
  }

  lastTimeMillis = millis();
}

void sendCommand(String command) {
  lastSentCommand = command;
  Serial1.print(command);
  Serial1.print("\n");
}

void switchOffChannelsExcept(String name) {
  for(int i = 0; i < channelsCount; ++i) {
    if(channels[i].name != name && !channels[i].isFxChannel) {
      channels[i].previousState = channels[i].state;
      channels[i].state = 0;
    }
  }
}

bool handleChannel(Channel &ch, int diffMillis, int currentTimeMillis) {
  ch.currentSwitchState = digitalRead(ch.switchPin);


  if(ch.currentSwitchState != ch.previousSwitchState && (currentTimeMillis-ch.lastSwitched) > 100) {
    if(ch.currentSwitchState == LOW) {
      ch.pressedMillis = 0;

      if(ch.isFxChannel) {
        ch.saveState = 1;
        
        //FX channels can be switched on and off independently
        if(ch.state == 0) {
          ch.state = 1;
          sendCommand("{\"action\":\"fxon\",\"channel\":\"" + ch.name + "\"}");
        }
        else {
          ch.state = 0;
          sendCommand("{\"action\":\"fxoff\",\"channel\":\"" + ch.name + "\"}");
        }
        
      } else {
        //Non FX channels are dependent. Only one non-FX channel can be active
        //switch off all other channels
        switchOffChannelsExcept(ch.name);
        
        if(ch.state == 1 && ch.hasSubChannel) {
          ch.state = 2;
          ch.ledStateCounter = 0;
          ch.saveState = 1;
        } else if(ch.state == 2) {
          ch.state = 1;
          ch.saveState = 2;
        } else {
          if(ch.previousState == 0)ch.previousState = 1;
          ch.state = ch.previousState;
          ch.saveState = ch.previousState;
        }

        if(ch.state == 1) {
          sendCommand("{\"action\":\"channelswitch\",\"channel\":\"" + ch.name + "\"}");
        } else {
          sendCommand("{\"action\":\"channelswitch\",\"channel\":\"" + ch.name + "-sub\"}");
        }
      }
    }

    ch.previousSwitchState = ch.currentSwitchState;
  }


  if(ch.currentSwitchState == LOW) {
    ch.lastSwitched = currentTimeMillis;
  }


  //save blinking
  bool currentlySaving = false;
  int saveState = HIGH;
  if(ch.currentSwitchState == LOW) {
    ch.pressedMillis += diffMillis;

    if(ch.pressedMillis >= saveTimeStartMillis) {
      currentlySaving = true;
      
      if((ch.pressedMillis / saveBlinkTimeMillis) % 2 == 1) {
        saveState = LOW;
      }
    }

    if(ch.pressedMillis > saveTimeMillis) {
      if(ch.saveState == 2) {
        sendCommand("{\"action\":\"channelsave\",\"channel\":\"" + ch.name + "-sub\", \"isFX\":" + (ch.isFxChannel ? "true" : "false") + "}");
      } else {
        sendCommand("{\"action\":\"channelsave\",\"channel\":\"" + ch.name + "\", \"isFX\":" + (ch.isFxChannel ? "true" : "false") + "}");
      }

      //restore save state
      
      if(ch.state != ch.saveState) {
        ch.state = ch.saveState;

        if(ch.isFxChannel) {
          sendCommand("{\"action\":\"fxon\",\"channel\":\"" + ch.name + "\"}");
        } else {
          if(ch.state == 1) {
            sendCommand("{\"action\":\"channelswitch\",\"channel\":\"" + ch.name + "\"}");
          } else {
            sendCommand("{\"action\":\"channelswitch\",\"channel\":\"" + ch.name + "-sub\"}");
          }
        }
      }
      
      ch.pressedMillis = 0;
    }
  }


  //sub channel blinking
  int subChannelState = HIGH;
  if (ch.state == 2 || currentlySaving) {
    ch.ledStateCounter += diffMillis;

    if((ch.ledStateCounter / subBlinkTimeMillis) % 2 == 1) {
      subChannelState = LOW;
    }
  }


  if((ch.state == 0 && !currentlySaving) || saveState == LOW || subChannelState == LOW) {
    digitalWrite(ch.ledPin, LOW);
  } else {
    digitalWrite(ch.ledPin, HIGH);
  }

  
  return (ch.currentSwitchState == LOW);
}
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

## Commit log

2024-01-10 Added Footswitch arduino code
2024-03-18 Changed app, added mockup service and next/prev buttons
2024-03-25 Added blender file
    [piamp.blend]
2024-03-25 Added front plate svg
2024-03-25 added holders
    [arduino-holder.stl, main-switch-holder.stl, screen-holder1.stl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]
2024-04-15 Imroved server side controls, added poweroff button
2024-04-19 Fixed Controls, almost no more bugs
    [Controls.ino]
2024-05-23 Added drawings
    [Spacer-encoder.stl, fan-holder.stl, feet.stl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]
